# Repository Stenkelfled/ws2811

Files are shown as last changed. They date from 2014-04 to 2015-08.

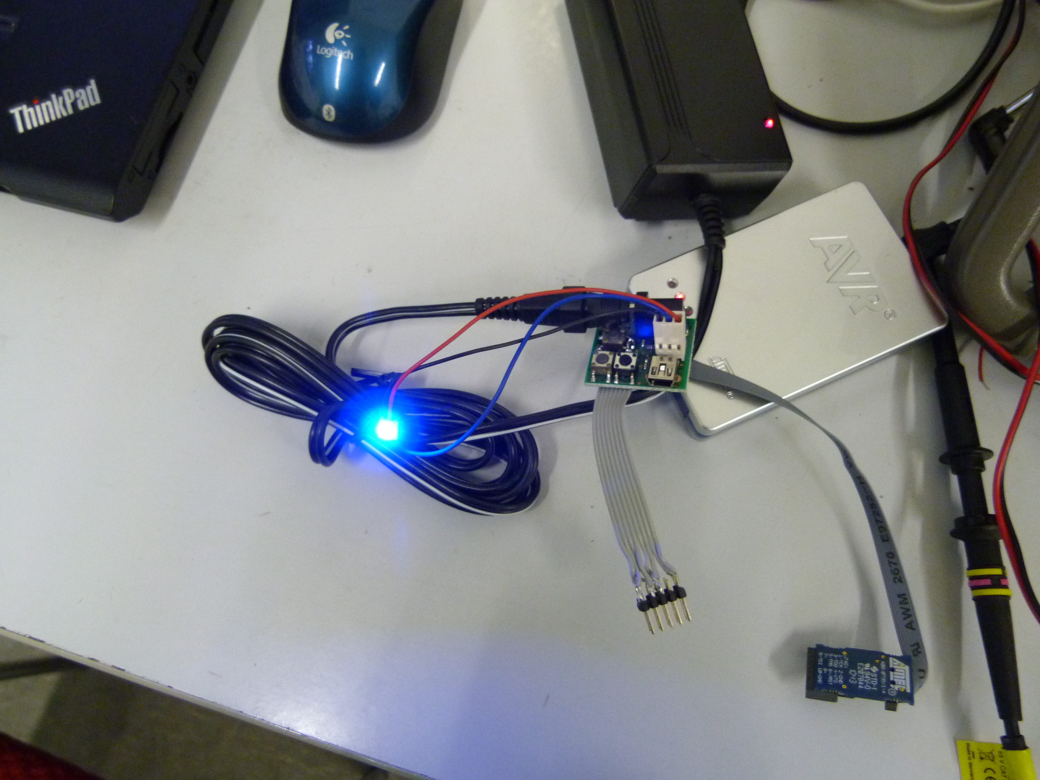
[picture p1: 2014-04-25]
demo.JPG

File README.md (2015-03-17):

# ws2811
WS2811 LED microcontroller driver with USB-connection and UserInterface for PC

Another Project for a WS2811 LED-strip. The clue here is, that the controller board is accessible via USB and that you can control the LEDs from you PC/Laptop.

Includes:
- Electronics design with ATXMEGA
- code for the xmega
- an UserInterface for a pc to communicate with the microcontroller written with Qt

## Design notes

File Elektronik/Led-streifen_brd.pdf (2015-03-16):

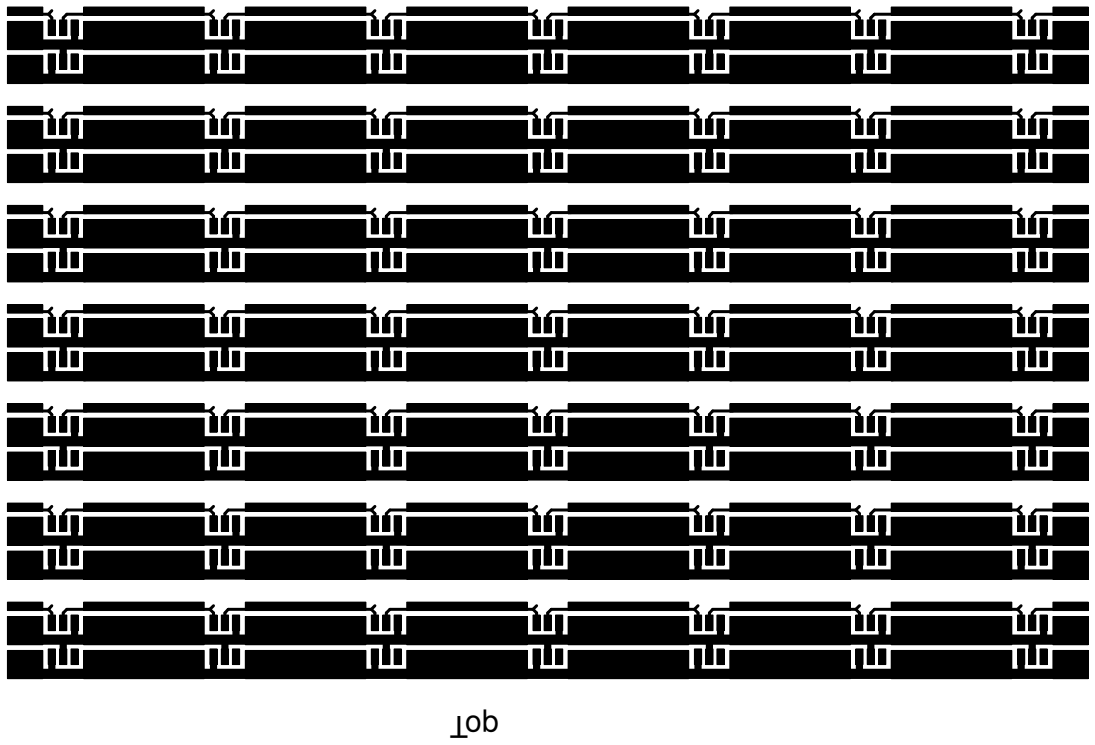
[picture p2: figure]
Top

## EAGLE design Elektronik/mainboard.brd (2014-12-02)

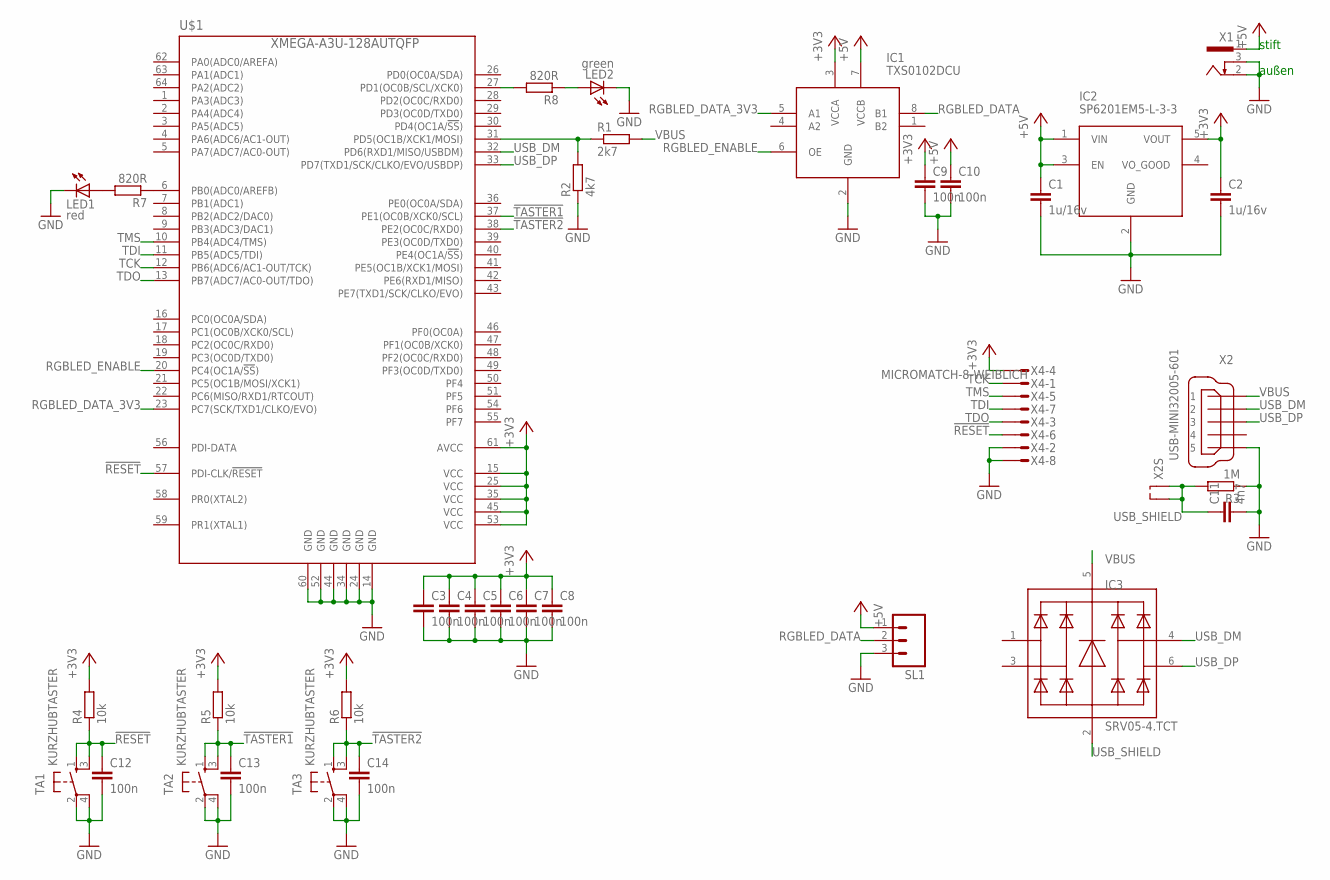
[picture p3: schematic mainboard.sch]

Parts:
C1, C2: 1u/16v; C0603
C3, C4, C5, C6, C7, C8, C9, C10, C12, C13, C14: 100n; C0603
C11: 4n7; C0603
IC1: TXS0102DCU; DCU8
IC2: SP6201EM5-L-3-3; SOT23-5
IC3: SRV05-4.TCT; SOT23-6
LED1: red; CHIPLED_0603
LED2: green; CHIPLED_0603
R1: 2k7; R0603
R2: 4k7; R0603
R3: 1M; R0603
R4, R5, R6: 10k; R0603
R7, R8: 820R; R0603
SL1: M03; 03P
TA1, TA2, TA3: KURZHUBTASTER; TA93XX
U$1: XMEGA-A3U-128AUTQFP; TQFP64
X1: 733980-62
X2: USB-MINI32005-601; 32005-601
X4: MICROMATCH-8-WEIBLICH; MICROMATCH-8

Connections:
!RESET!: C12.1, R4.1, TA1.1 (S), TA1.3 (S1), U$1.57 (PDI-CLK/!RESET), X4.6
!TASTER1!: C13.1, R5.1, TA2.1 (S), TA2.3 (S1), U$1.37 (PE1(OC0B/XCK0/SCL))
!TASTER2!: C14.1, R6.1, TA3.1 (S), TA3.3 (S1), U$1.38 (PE2(OC0C/RXD0))
+3V3: C2.1, C3.1, C4.1, C5.1, C6.1, C7.1, C8.1, C9.1, IC1.3 (VCCA), IC2.5 (VOUT), R4.2, R5.2, R6.2, U$1.15 (VCC), U$1.25 (VCC), U$1.35 (VCC), U$1.45 (VCC), U$1.53 (VCC), U$1.61 (AVCC), X4.4
+5V: C1.1, C10.1, IC1.7 (VCCB), IC2.1 (VIN), IC2.3 (EN), SL1.1, X1.1
GND: C1.2, C2.2, C3.2, C4.2, C5.2, C6.2, C7.2, C8.2, C9.2, C10.2, C11.2, C12.2, C13.2, C14.2, IC1.2 (GND), IC2.2 (GND), LED1.C, LED2.C, R2.1, R3.1, SL1.3, TA1.2, TA1.4 (P1), TA2.2, TA2.4 (P1), TA3.2, TA3.4 (P1), U$1.14 (GND), U$1.24 (GND), U$1.34 (GND), U$1.44 (GND), U$1.52 (GND), U$1.60 (GND), X1.2, X1.3, X2.5, X4.2, X4.8
unnamed: R1.1, R2.2, U$1.31 (PD5(OC1B/XCK1/MOSI))
unnamed: R7.1, U$1.6 (PB0(ADC0/AREFB))
unnamed: LED1.A, R7.2
unnamed: R8.2, U$1.27 (PD1(OC0B/SCL/XCK0))
unnamed: LED2.A, R8.1
RGBLED_DATA: IC1.8 (B1), SL1.2
RGBLED_DATA_3V3: IC1.5 (A1), U$1.23 (PC7(SCK/TXD1/CLKO/EVO))
RGBLED_ENABLE: IC1.6 (OE), U$1.20 (PC4(OC1A/!SS!))
TCK: U$1.12 (PB6(ADC6/AC1-OUT/TCK)), X4.1
TDI: U$1.11 (PB5(ADC5/TDI)), X4.7
TDO: U$1.13 (PB7(ADC7/AC0-OUT/TDO)), X4.3
TMS: U$1.10 (PB4(ADC4/TMS)), X4.5
USB_DM: IC3.4 (3), U$1.32 (PD6(RXD1/MISO/USBDM)), X2.2
USB_DP: IC3.6 (4), U$1.33 (PD7(TXD1/SCK/CLKO/EVO/USBDP)), X2.3
USB_SHIELD: C11.1, IC3.2 (A), R3.2, X2.M1 (S1), X2.M2 (S2)
VBUS: IC3.5 (K), R1.2, X2.1

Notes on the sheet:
stift
außen

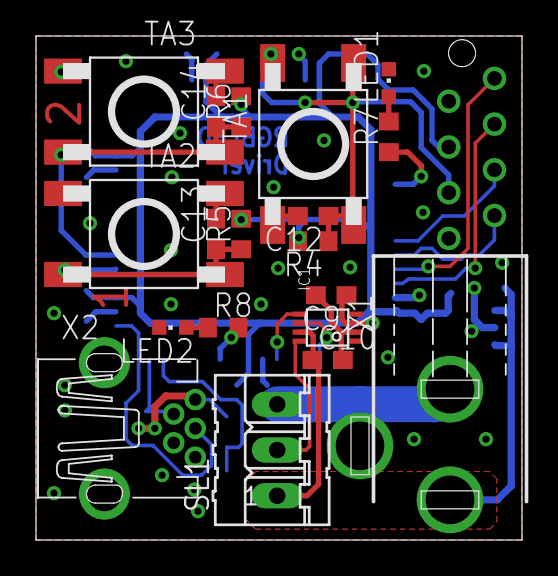
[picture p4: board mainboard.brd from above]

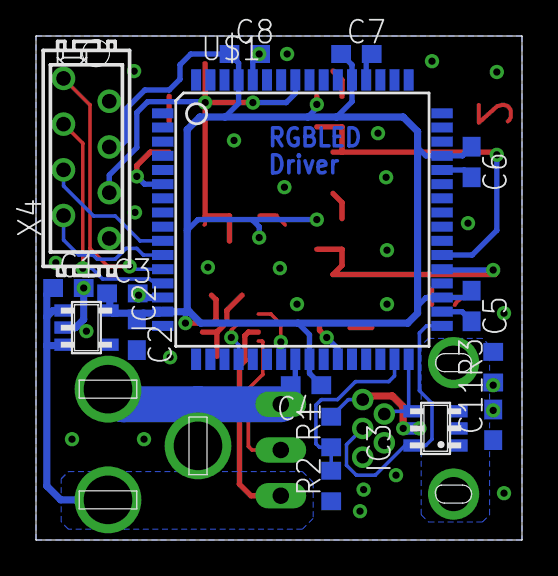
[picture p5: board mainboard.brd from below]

Board: 2 copper layers, 27.0 x 28.0 mm, 35 parts (16 on the bottom side), 22 nets.

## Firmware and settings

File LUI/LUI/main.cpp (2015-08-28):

#include "lui.h"
#include <QApplication>
#include <QDebug>

int main(int argc, char *argv[])
{
    QApplication a(argc, argv);
    QFile file(":/styles/splitter.css");
    if(file.open(QFile::ReadOnly)){
        QString style_sheet = QString::fromLatin1(file.readAll());
        file.close();
        a.setStyleSheet(style_sheet);
    } else {
        qDebug() << "splitter-style-file not found";
    }
    Lui w;
    w.show();

    return a.exec();
}

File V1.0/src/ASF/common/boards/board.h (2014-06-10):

/**
 * \file
 *
 * \brief Standard board header file.
 *
 * This file includes the appropriate board header file according to the
 * defined board (parameter BOARD).
 *
 * Copyright (c) 2009-2013 Atmel Corporation. All rights reserved.
 *
 * \asf_license_start
 *
 * \page License
 *
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
 * 3. The name of Atmel may not be used to endorse or promote products derived
 *    from this software without specific prior written permission.
 *
 * 4. This software may only be redistributed and used in connection with an
 *    Atmel microcontroller product.
 *
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
 * \asf_license_stop
 *
 */

#ifndef _BOARD_H_
#define _BOARD_H_

/**
 * \defgroup group_common_boards Generic board support
 *
 * The generic board support module includes board-specific definitions
 * and function prototypes, such as the board initialization function.
 *
 * \{
 */

#include "compiler.h"

#ifdef __cplusplus
extern "C" {
#endif


/*! \name Base Boards
 */
//! @{
#define EVK1100                     1  //!< AT32UC3A EVK1100 board.
#define EVK1101                     2  //!< AT32UC3B EVK1101 board.
#define UC3C_EK                     3  //!< AT32UC3C UC3C_EK board.
#define EVK1104                     4  //!< AT32UC3A3 EVK1104 board.
#define EVK1105                     5  //!< AT32UC3A EVK1105 board.
#define STK600_RCUC3L0              6  //!< STK600 RCUC3L0 board.
#define UC3L_EK                     7  //!< AT32UC3L-EK board.
#define XPLAIN                      8  //!< ATxmega128A1 Xplain board.
#define STK600_RC064X              10  //!< ATxmega256A3 STK600 board.
#define STK600_RC100X              11  //!< ATxmega128A1 STK600 board.
#define UC3_A3_XPLAINED            13  //!< ATUC3A3 UC3-A3 Xplained board.
#define UC3_L0_XPLAINED            15  //!< ATUC3L0 UC3-L0 Xplained board.
#define STK600_RCUC3D              16  //!< STK600 RCUC3D board.
#define STK600_RCUC3C0             17  //!< STK600 RCUC3C board.
#define XMEGA_B1_XPLAINED          18  //!< ATxmega128B1 Xplained board.
#define XMEGA_A1_XPLAINED          19  //!< ATxmega128A1 Xplain-A1 board.
#define STK600_RCUC3L4             21  //!< ATUCL4 STK600 board
#define UC3_L0_XPLAINED_BC         22  //!< ATUC3L0 UC3-L0 Xplained board controller board
#define MEGA1284P_XPLAINED_BC      23  //!< ATmega1284P-Xplained board controller board
#define STK600_RC044X              24  //!< STK600 with RC044X routing card board.
#define STK600_RCUC3B0             25  //!< STK600 RCUC3B0 board.
#define UC3_L0_QT600               26  //!< QT600 UC3L0 MCU board.
#define XMEGA_A3BU_XPLAINED        27  //!< ATxmega256A3BU Xplained board.
#define STK600_RC064X_LCDX         28  //!< XMEGAB3 STK600 RC064X LCDX board.
#define STK600_RC100X_LCDX         29  //!< XMEGAB1 STK600 RC100X LCDX board.
#define UC3B_BOARD_CONTROLLER      30  //!< AT32UC3B1 board controller for Atmel boards
#define RZ600                      31  //!< AT32UC3A RZ600 MCU board
#define SAM3S_EK                   32  //!< SAM3S-EK board.
#define SAM3U_EK                   33  //!< SAM3U-EK board.
#define SAM3X_EK                   34  //!< SAM3X-EK board.
#define SAM3N_EK                   35  //!< SAM3N-EK board.
#define SAM3S_EK2                  36  //!< SAM3S-EK2 board.
#define SAM4S_EK                   37  //!< SAM4S-EK board.
#define STK600_RCUC3A0             38  //!< STK600 RCUC3A0 board.
#define STK600_MEGA                39  //!< STK600 MEGA board.
#define MEGA_1284P_XPLAINED        40  //!< ATmega1284P Xplained board.
#define SAM4S_XPLAINED             41  //!< SAM4S Xplained board.
#define ATXMEGA128A1_QT600         42  //!< QT600 ATXMEGA128A1 MCU board.
#define ARDUINO_DUE_X              43  //!< Arduino Due/X board.
#define STK600_RCUC3L3             44  //!< ATUCL3 STK600 board
#define SAM4L_EK                   45  //!< SAM4L-EK board.
#define STK600_MEGA_RF             46  //!< STK600 MEGA RF EVK board.
#define XMEGA_C3_XPLAINED          47  //!< ATxmega384C3 Xplained board.
#define STK600_RC032X              48  //!< STK600 with RC032X routing card board.
#define SAM4S_EK2                  49  //!< SAM4S-EK2 board.
#define XMEGA_E5_XPLAINED          50  //!< ATxmega32E5 Xplained board.
#define SAM4E_EK                   51  //!< SAM4E-EK board.
#define ATMEGA256RFR2_XPLAINED_PRO 52  //!< ATmega256RFR2 Xplained Pro board.
#define SAM4S_XPLAINED_PRO         53  //!< SAM4S Xplained Pro board.
#define SAM4L_XPLAINED_PRO         54  //!< SAM4L Xplained Pro board.
#define ATMEGA256RFR2_ZIGBIT       55  //!< ATmega256RFR2 zigbit
#define XMEGA_RF233_ZIGBIT         56  //!< ATxmega256A3U with AT86RF233 zigbit
#define XMEGA_RF212B_ZIGBIT        57  //!< ATxmega256A3U with AT86RF212B zigbit
#define SAM4S_WPIR_RD              58  //!< SAM4S-WPIR-RD board.
#define SAMD20_XPLAINED_PRO        59  //!< SAMD20 Xplained PRO board
#define SAM4L8_XPLAINED_PRO        60  //!< SAM4L8 Xplained Pro board.
#define SAM4N_XPLAINED_PRO         61  //!< SAM4N-XPLAINED-PRO board.
#define XMEGA_A3_REB_CBB           62  //!< SAM4L8 Xplained Pro board.
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

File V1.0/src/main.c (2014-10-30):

/**
 * \file
 *
 * \brief Empty user application template
 *
 */

/**
 * \mainpage User Application template doxygen documentation
 *
 * \par Empty user application template
 *
 * Bare minimum empty user application template
 *
 * \par Content
 *
 * -# Include the ASF header files (through asf.h)
 * -# Minimal main function that starts with a call to board_init()
 * -# "Insert application code here" comment
 *
 */

/*
 * Include header files for all drivers that have been imported from
 * Atmel Software Framework (ASF).
 */
#include <asf.h>
#include <util/delay.h>

#include <config.h>
#include <eeprom.h>
#include <ee_interpreter.h>
#include <leds.h>
#include <ledbuffer.h>
#include <rgbhsv.h>
#include <usb.h>
#include <usbprint.h>

uint8_t mode = 0;

/*void run_from_eeprom_ready_fcn(void);
void run_from_eeprom(void);

void run_from_eeprom_ready_fcn(void){
	
}

void run_from_eeprom(void){
	while(eeprom_get_read_access() != RET_OK){}
	uint8_t group_id = 0;
	uint8_t group_count;
}*/

int main (void)
{
	init_interrupts();
	init_clock();
	init_board();
	init_ports();
	init_usart();
	init_dma(ledbuffer_get_data_pointer());
	init_eeprom();
	start_leds();
	usb_print_init();
	sei();
	//LED_RD_ON
	
	interprete_eeprom();
	
	usb_start();

 	//_delay_ms(1000);

// 	int8_t uart_char;
// 	while(1){
// 		uart_char = udi_cdc_getc();
// 		TCC2.LCNT = uart_char;
// 		asm volatile ("nop");
// 		if(udi_cdc_is_tx_ready()){
// 			udi_cdc_putc('k');
// 		}
// 	}
	
	while(1){
		asm volatile ("nop");
	}


	/*uint8_t gid = 0;
    define_group(gid,0,LED_COUNT-1,1);
	
	rgbcolor_t clr={0x00,0x00,0x00};

	hsvcolor_t hsvcol;
	hsvcol.sat = 255;
	hsvcol.val = 255;
	hsvcol.hue = 0;

	while(1){
		cli();
		switch(mode){
			case 0:	
				hsvcol.hue +=1;
				if(hsvcol.hue == 360) hsvcol.hue = 0;
				clr = hsv2rgb(hsvcol);
				break;
			case 1:
				set_predefined_color(&clr,CLR_RED);
				break;
			case 2:
				set_predefined_color(&clr,CLR_GREEN);
				break;
			case 3:
				set_predefined_color(&clr,CLR_BLUE);
				break;
			case 4:
				set_predefined_color(&clr,CLR_WHITE);
				break;
		}
		sei();
		color_group(gid,clr);
		fill_buffer();
		refresh_leds();
		_delay_ms(20);
	}*/
	// Insert application code here, after the board has been initialized.
}

ISR(PORTE_INT0_vect){ //Button 1 pressed
	if(++mode > 4){
		mode = 0;
	}
	usb_print("Button 1\n");
}

ISR(PORTE_INT1_vect){ //Button 2 pressed
	if(mode-- == 0){
		mode = 4;
	}
	usb_print("Button 2\n");
}

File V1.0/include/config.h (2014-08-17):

/*
 * config.h
 *
 * Created: 07.05.2014 17:39:17
 *  Author: stenkelfled
 */ 


#ifndef CONFIG_H_
#define CONFIG_H_
#include <avr/io.h>
#include <global.h>

#define TRUE			(1)
#define FALSE			(0)
#define YES				(TRUE)

#define USB_DEBUG_ENABLE	(YES)

#define LED_COUNT		(GLOBAL_LED_COUNT)

#define BUTTON_PORT		(PORTE)
#define BUTTON1_PIN		(1)
#define BUTTON2_PIN		(2)

#define USB_PORT		(PORTD)
#define USB_POWER_PIN	(5)

void init_interrupts(void);
void init_clock(void);
void init_ports(void);


#endif /* CONFIG_H_ */

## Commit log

2014-01-11 * Initial Commit. * added ASF for SystemClock and IOs * added Initialization for SystemClock and IOs
    [1LED.brd, 1LED.sch, mainboard.brd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]
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2014-02-22 Schaltplan und Layout hinzugefügt
    [leds.brd, leds.sch]
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2014-04-26 * LED-Bitreihenfolge korrigiert
2014-04-26 * neue Sende- und Resetfunktion für die LEDs
    [main.c]
2014-04-27 * Anfang für eine EURO-Platine mit LED-Footprints
    [LED-Platinen.brd, LED-Platinen.sch, leds.brd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]
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2014-04-29 * Senden ohne unnötige Wartezeiten---wenn der Sendevorgang abgeschlossen ist, dann ist auch schluss
2014-04-30 * standartmäßig datenleitung auf low. *TODO: gucken, dass am Anfang vom Senden die Datenleitung nicht zu lange high ist
2014-05-01 * SO. Jetzt wird auch die gewählte Farbe richtig angezeigt. Lösung war, die gesamte Zeit einfach nur 0 zu senden (also Leitung ständig Low halten). Wird im Moment per DMA gemacht, weil der UART beim 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
2014-05-01 * RGB-HSV-Konvertierung hinzugefügt * PROBLEM: die LED flackert
    [main.c]
2014-05-04 * DMA-CH1 ausschalten, bevor DMA-CH0 eingeschaltet wird --> Jetzt leuchtet sie schön gleichmäßig - ohne hässliches Blitzen
2014-05-04 * Europlatine mit 60 Footprints zum anschließen
    [Leds.brd, Platinenanordnung.xlsx]
2014-05-04 * altes Zeug gelöscht
    [LED-Platinen.brd, LED-Platinen.sch]
2014-05-07 * bisschen ausgemistet * schnelles Farbe setzen hinzugefügt * Buttons in Betrieb genommen
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2014-06-28 [USB-Driver]zumindest das Enumerieren funktioniert jetzt mit dem ASF-Treiber. Referenzimplementierung hinzugefügt, aber die ist eigenlich nicht mehr nötig
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2014-06-28 [USB-Driver] Erkennung der Power-line - funktioniert aber hardwaremäßig noch nicht so gut, weil die Datenleitungen die Powerline hochziehen
2014-07-01 [Elektronik] Spannungsteiler für VBUS angepasst, damit die Pullups der Datenleitungen die VBUS-leitung nicht über die ESD-Dioden nach oben ziehen
    [mainboard.brd, mainboard.sch]
2014-07-01 [USB-driver] Der Treiber ist jetzt interruptbasiert und wartet auf eine Präambel, bevor er Daten annimmt
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2014-07-07 * Debugausgaben per USB juhuuu * Statemachinekernel läuft auch - nur die Statemachine an sich ist noch nicht bugfrei
    [config.h, main.c]
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2014-07-07 * debugpuffer-probleme behoben. * Leds leuchten bei RGB (0xFF 0xFF 0xFF) nicht mehr. Vielleicht ist die Austastlücke zu kurz?
2014-08-03 Anfänge für das UI mit QT. Zumindest der serielle Port funktioniert schon
2014-08-03 bisschen spät für einen commit, daher ist das Log nicht so zuverlässig: wahrscheinlich das USB-Debug verbessert und die Auswertung der USB-Daten erweitert
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2014-08-05 Gruppe kann jetzt Leds enthalten. Die Positionierung der Gruppen funktoniert noch nicht
2014-08-09 Items sind jetzt alle selectable
    [mainboard.brd, mainboard.sch]
2014-08-10 [LUI] Led von Gruppe entfernen geht. -> das muss auch bei mittleren Leds sichtbar werden; leere Gruppen müssen entfernt werden
2014-08-11 [LUI] gruppieren und Gruppierung auflösen geht. Jetzt noch Markieren, indem man ein Viereck zieht
2014-08-12 [LUI]* Verschieben von Leds und Gruppen funktioniert, Gruppenhintergrund wird dann auch erweitert * Auswahl von Leds intuitiver gemacht
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2014-08-13 [LUI] Farbe setzen für Leds funktioniert, inkl. Helligkeit einstellen - bis auf die benutzerdefinierte Farbe.
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2014-08-17 [LUI] Puffer für USB-Daten [AVR] Auswertung der USB-Daten ohne evaluator, weil einfacher geworden und der Evaluator wird später noch benötigt
2014-08-17 [LUI] Bug in der Farbgebung behoben
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2014-08-17 [LUI] Auch wenn die gleiche Farbe rauskommt, ist HSV leider nicht gleich RGB
2014-08-17 [LUI] Beim Gruppieren wird jetzt die Reihenfolge der LEDs beachtet. Hat allerdings im Moment den Nachteil, dass man die Leds nicht mehr verschieben kann.
2014-08-18 [LUI] angezeigten VALUE der Farben so korrigiert, dass auch bei niedrigem originalem VALUE noch die Farbe zu sehen ist
    [settings.h]
2014-08-19 [LUI]* Leds kennen ihre Position in der Gruppe * Gruppenhintergrund vergrößert sich, wenn eine LED bewegt wird
2014-09-02 [LUI] Drag&Drop für die Leds vorbereitet. Leider schnipsen die nach dem drop noch nicht an die gewünschte Position
2014-09-03 [LUI] Die Leds schnipsen nicht mehr(aber ich weiß nicht richtig, warum - ich hab nur die Propagation von mouseMoveEvent entfern). Stilisierte Led beim verschieben.
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2014-09-06 [LUI] endlich funktionieren die Events (wieder) so, wie sie sollen. Jetzt nur noch Leben rein...
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2014-09-09 [LUI] oller Eventnachbau in der Scene. Jetzt funktioniert auch das Verschieben der Leds innerhalb von Gruppen, die nich auf (0,0) liegen wieder
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2014-09-11 [LUI] Kontextmenu für die Gruppen hinzugefügt. Man kann ihnen jetzt Namen geben und die Anordnung zwischen horizontal und vertikal umschalten
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2014-10-07 [LUI] wichtiger Nachtrag: jetzt werden beim löschen der Listeneiträge auch deren Pointer gelöscht
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2014-10-23 [LUI] Cursor für die Sequenzen eingefügt. Passt sich auch schon automatisch an verschiedene Gruppenanzahlen an, funktioniert aber noch nicht
2014-10-24 [LUI] Cursor mit Leben gefüllt. Außerdem können den SequenceItems jetzt Farben zugewiesen werden, die auch in der Gruppe angezeigt werden.
2014-10-24 [LUI] wenn eine neue Gruppe erzeugt wird, hat die eine Standardfarbe - und die wird bitteschö
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2014-10-24 [LUI] jetzt sind auch mehrere SequenceItems möglich. Tabs werden gewechselt, wenn Gruppe oder Item angeklickt wird
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2014-10-29 [LUI] offset für die Gruppenadressen korrigiert
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2014-10-31 [uC] FIX: eine einzelne LED in der Gruppe war bisher nicht möglich
2014-10-31 HOTFIX: man kann im LUI mehr Gruppen anlegen, als der uC versteht. FIX: es gibt jetzt so viele Gruppen, wie LEDs, aber das funktioniert auf Dauer nicht
2014-12-02 [Elektronik] Layout für Fertigung in der Uni angepasst
    [mainboard.brd, mainboard.sch]
2015-01-27 [Elektronik] Anfänge für neue Streifenplatinen
    [Led-streifen.brd, mainboard.sch]
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2015-03-16 [Elektronik] altes Zeug entfernt
    [1LED.brd, 1LED.sch, Leds.brd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]
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2015-12-04 [LUI] more documentation. Current problem: how to ensure, that no LedItem is removed from the scene by dropping it outside
2016-01-03 New QGraphicsSceneDragDropEvent ensures, that any LED dropped outside its scene will be replaced on an empty spot inside the scene.
    [settings.h]
